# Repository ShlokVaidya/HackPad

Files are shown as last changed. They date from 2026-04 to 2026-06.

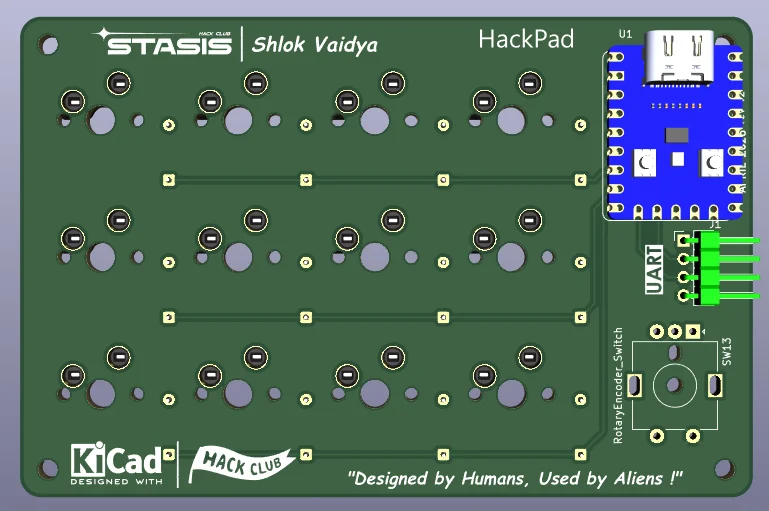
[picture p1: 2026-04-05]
PDFs/1775170877334-m3it0k.webp

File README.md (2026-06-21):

# HackPad

A 12-key macropad I built as my second hardware project for Stasis, designed to pair with my 60% keyboard for editing, shortcuts, media control, etc...

Hi there, this is my fully custom keypad from scratch, and I tried to keep it clean, practical, and actually buildable.

## Demo Video

<video src="./HackPad.mp4" controls width="1080">
  Your browser does not support embedded videos. You can watch the demo here: <a href="./HackPad.mp4">HackPad.mp4</a>.
</video>

[Open the demo video](./HackPad.mp4)

Note: The demo vid is working but u need to download to view it as it exceeds the 100mb Github limit. 

## Quick Project Summary

- Project: 3x4 macropad + rotary encoder
- MCU: RP2040 Zero
- Switches: 12x MX-style
- Extra input: 1x EC11 rotary encoder with push switch
- Matrix: 3 rows x 4 columns
- PCB size target: about 100mm x 65mm
- Case workflow: KiCad PCB export -> Onshape assembly -> custom bottom case + plate

## Why I Made This

I wanted a dedicated macropad next to my keyboard for common shortcuts (copy/paste, app switching, media, timeline scrubbing, etc.) and I wanted to learn the full flow:

1. keyboard layout planning
2. schematic capture
3. PCB routing
4. case CAD around real board geometry

## Features

- 12 programmable keys (MX style)
- Rotary encoder with click for volume/scroll/tool size/etc.
- RP2040-based and easy to firmware-program
- Through-hole diodes for matrix
- UART header exposed
- Custom silkscreen logos for personality

## Bill of Materials (BOM)

From [production/bom.csv](production/bom.csv):

| Item | Qty | Notes |
|---|---:|---|
| RP2040 Zero module | 1 | Main controller |
| MX-style switches | 12 | 1u keys |
| 1N4148 diodes | 12 | Matrix diodes |
| EC11 rotary encoder (with switch) | 1 | Knob + click |
| 1x4 right-angle pin header | 1 | UART / expansion |

## Design Files Included

- Schematic: [PCB/HackPad.kicad_sch](PCB/HackPad.kicad_sch)
- PCB: [PCB/HackPad.kicad_pcb](PCB/HackPad.kicad_pcb)
- KiCad project: [PCB/HackPad.kicad_pro](PCB/HackPad.kicad_pro)
- Layout JSON: [PCB/keyboard-layout.json](PCB/keyboard-layout.json)
- Plate DXF: [PCB/plate.dxf](PCB/plate.dxf)
- CAD model: [CAD/HackPad.step](CAD/HackPad.step)
- Production files:
	- [production/bom.csv](production/bom.csv)
	- [production/positions.csv](production/positions.csv)
	- [production/designators.csv](production/designators.csv)
	- [production/netlist.ipc](production/netlist.ipc)

## Firmware

KMK firmware for this board is included in:

- [firmware/kmk/code.py](firmware/kmk/code.py)
- [firmware/kmk/README.md](firmware/kmk/README.md)

It is preconfigured for the exact matrix and encoder pins used in this PCB.

## Progress Pictures

### Research

Research start / Stasis planning

### Schematic Stage

Keyboard layout planning

Schematic routing

### PCB Stage

PCB routing

PCB front silkscreen

PCB back silkscreen

### CAD / Case Stage

CAD view 1

CAD view 2

CAD view 3

CAD view 4

CAD view 5

CAD view 6

## Time Spent (from Journal)

- Research: ~0.33h
- Schematic: ~2.25h
- PCB: ~3.25h
- CAD: ~3.45h

Total logged so far: ~9.3h

## What I Learned

- Importing the actual PCB into CAD early saves a lot of pain later.
- Matrix labeling in schematic makes routing way less confusing.
- Tiny mechanical details (insert depth, nut traps, plate thickness) matter a lot more than expected.
- Silkscreen art is optional, but morale is not.

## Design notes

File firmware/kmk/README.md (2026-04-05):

# HackPad Advanced Firmware (KMK)

This folder contains an advanced default firmware for the RP2040-Zero-based HackPad.

## What You Get

- Correct matrix pin mapping from your PCB
- Rotary encoder support (turn + click)
- 4 layers: Base, Nav, Media, System
- Tap-dance (`ESC` on single tap, `` ` `` on double tap)
- Layer-tap keys (tap sends key, hold changes layer)
- Chord combos:
  - `Copy + Paste` -> `Select All`
  - `Undo + Redo` -> `Save`

## Pin Mapping (from KiCad)

- Columns: `GP14 GP15 GP26`
- Rows: `GP27 GP28 GP29 GP13`
- Encoder A/B/SW: `GP10 GP11 GP12`

## Install Steps

1. Flash CircuitPython to the RP2040 Zero.
2. Download KMK and copy the `kmk` folder to the CIRCUITPY drive.
3. Copy [firmware/kmk/code.py](code.py) to the root of CIRCUITPY as `code.py`.
4. Replug the board.

## Layer Overview

- `Layer 0 (Base)`: editing shortcuts and layer access
- `Layer 1 (Nav)`: arrows, home/end, page movement
- `Layer 2 (Media)`: media transport and volume
- `Layer 3 (System)`: function keys and reset/boot helpers

The bottom row of Layer 0 is layer-tap:

- Left key: tap `Space`, hold Layer 1
- Middle key: tap `Enter`, hold Layer 2
- Right key: tap `Tab`, hold Layer 3

## Notes

- If the matrix scans inverted on first boot, switch
  `DiodeOrientation.ROW2COL` to `DiodeOrientation.COL2ROW` in [firmware/kmk/code.py](code.py).
- `KC.BOOT` and `KC.RESET` are provided on Layer 3 for recovery/reflash flows.

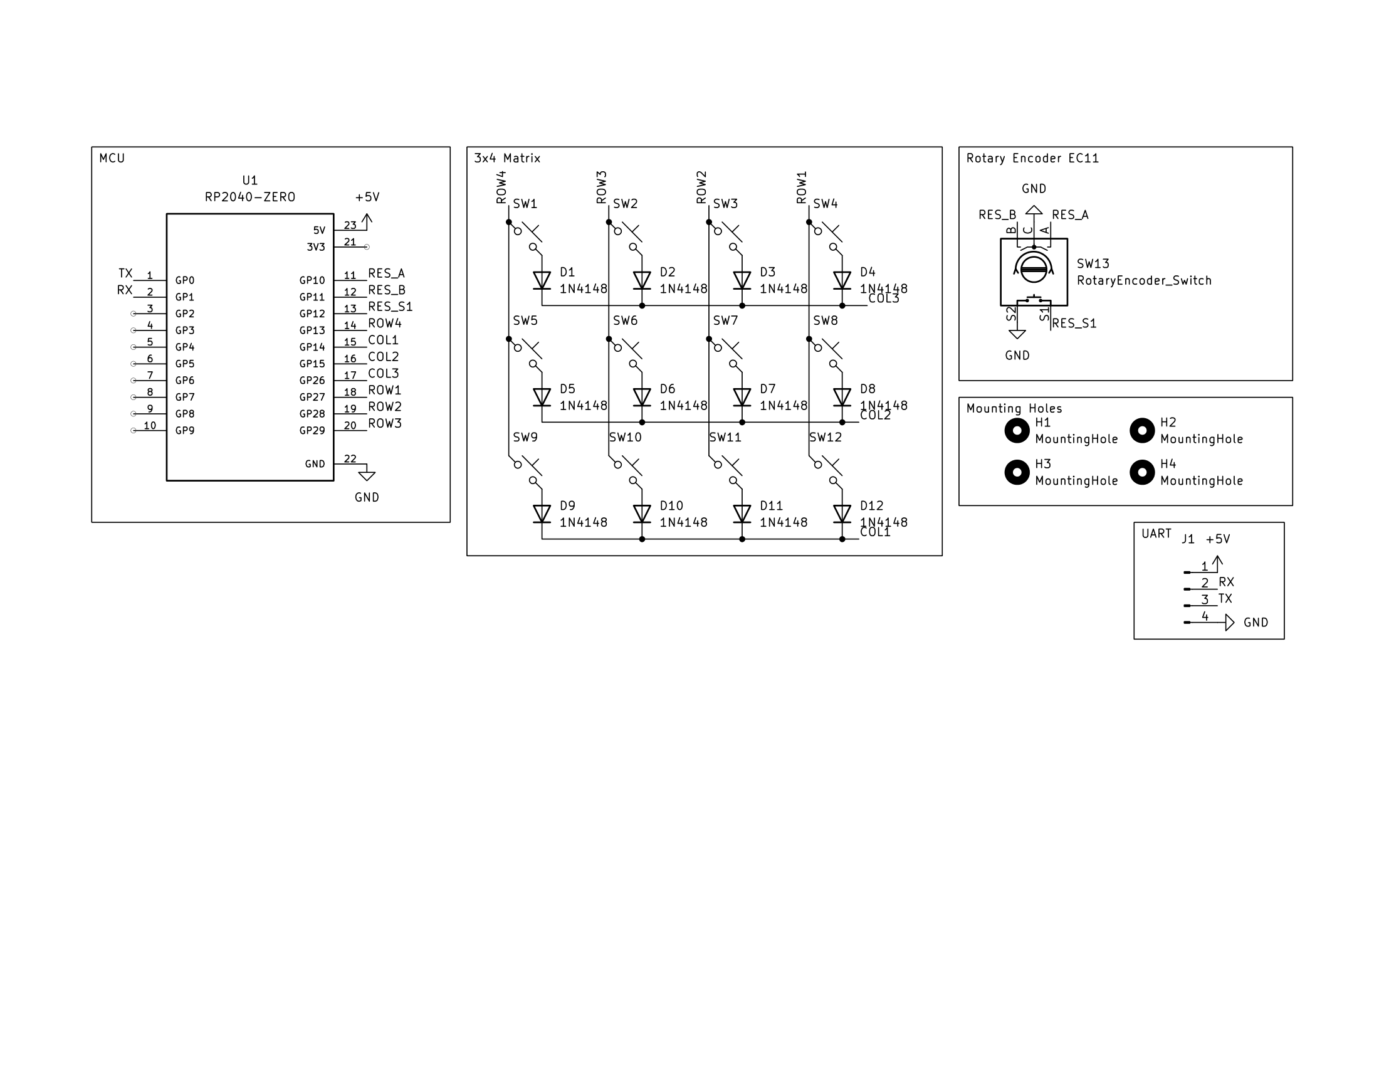
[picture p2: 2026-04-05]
PDFs/sch.png

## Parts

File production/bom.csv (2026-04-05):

Designator | Footprint | Quantity | Value | LCSC Part #
D1, D10, D11, D12, D2, D3, D4, D5, D6, D7, D8, D9 | D_DO-35_SOD27_P7.62mm_Horizontal | 12 | 1N4148
J1 | PinHeader_1x04_P2.54mm_Horizontal | 1 | Conn_01x04_Pin
SW1, SW10, SW11, SW12, SW2, SW3, SW4, SW5, SW6, SW7, SW8, SW9 | SW_MX_HS_KS-2P02B01-01_1u | 12 | SW_Push_45deg
SW13 | RotaryEncoder_Alps_EC11E-Switch_Vertical_H20mm_MountingHoles | 1 | RotaryEncoder_Switch
U1 | MODULE_RP2040-ZERO | 1 | RP2040-ZERO

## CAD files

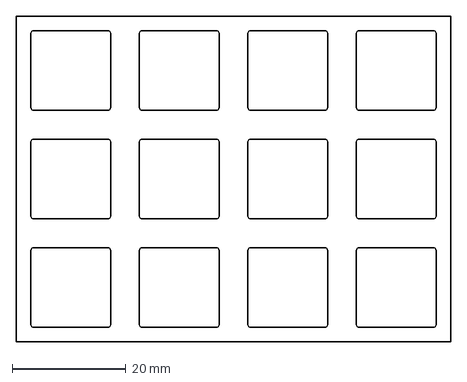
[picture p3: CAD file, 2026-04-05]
PCB/plate.dxf
76.2 x 57.1 mm

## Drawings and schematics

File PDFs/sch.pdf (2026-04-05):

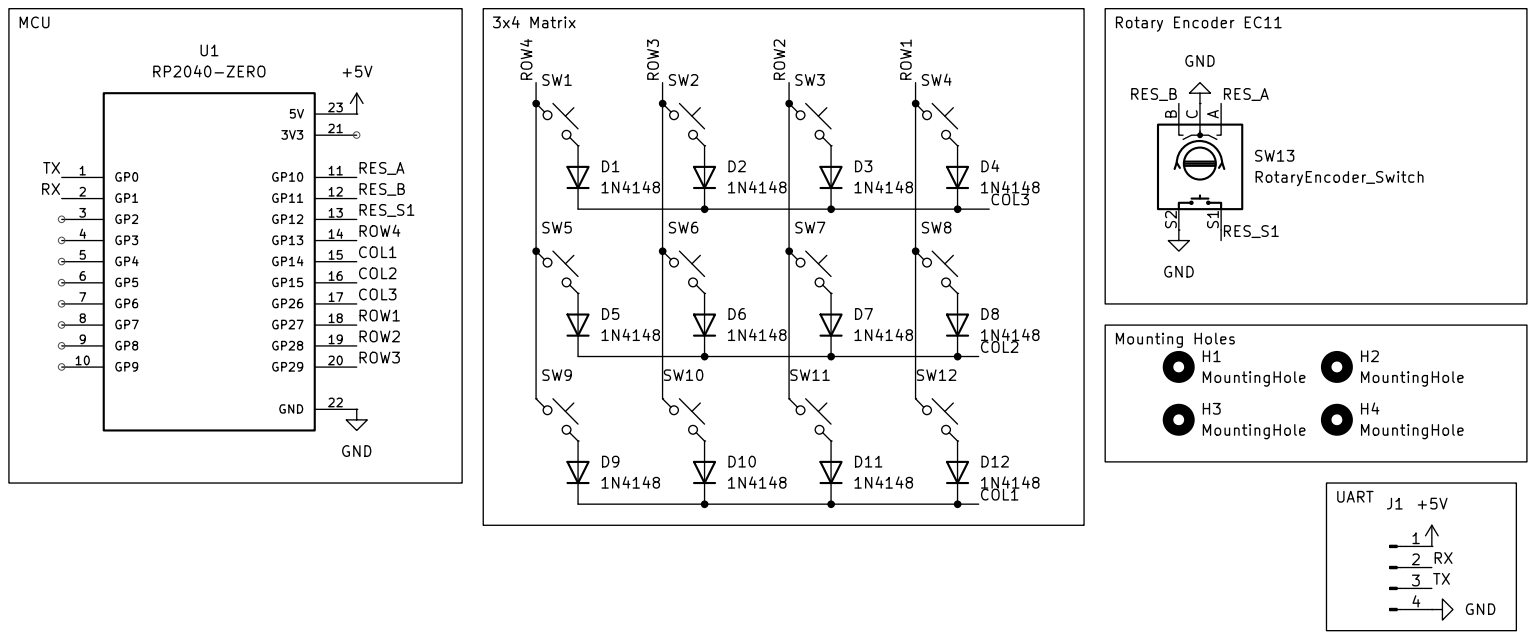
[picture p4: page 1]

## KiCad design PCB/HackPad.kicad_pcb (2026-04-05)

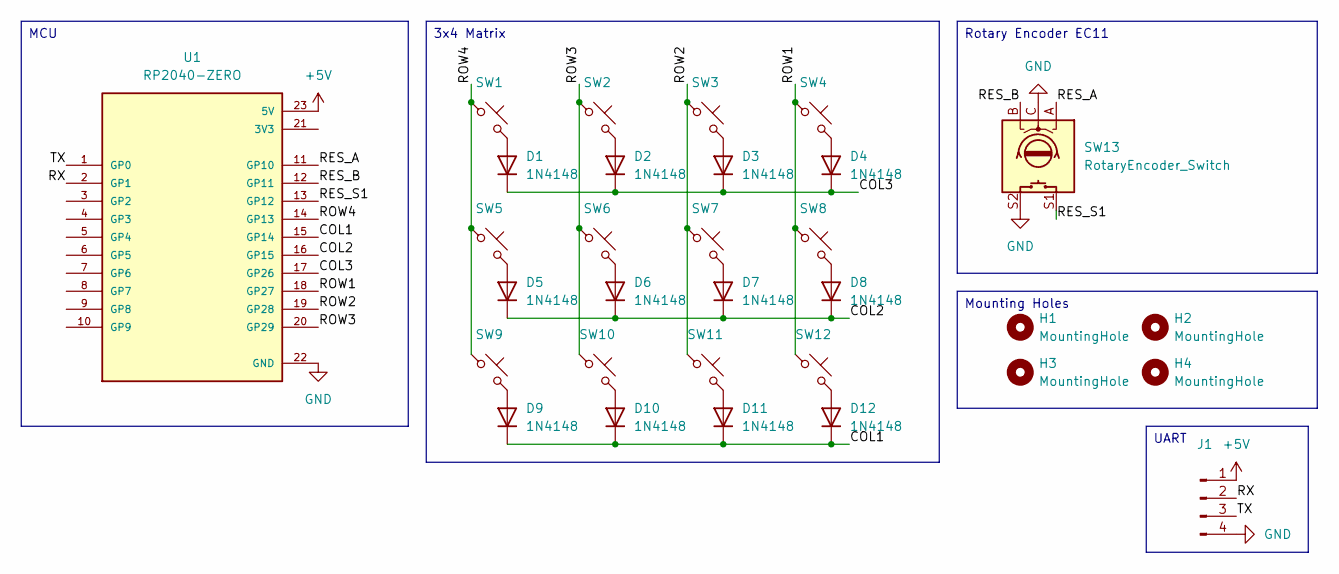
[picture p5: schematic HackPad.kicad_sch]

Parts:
D1, D2, D3, D4, D5, D6, D7, D8, D9, D10, D11, D12: 1N4148; D_DO-35_SOD27_P7.62mm_Horizontal
H1, H2, H3, H4: MountingHole; MountingHole_2.7mm_M2.5
J1: Conn_01x04_Pin; PinHeader_1x04_P2.54mm_Horizontal
SW1, SW2, SW3, SW4, SW5, SW6, SW7, SW8, SW9, SW10, SW11, SW12: SW_Push_45deg; SW_MX_HS_KS-2P02B01-01_1u
SW13: RotaryEncoder_Switch; RotaryEncoder_Alps_EC11E-Switch_Vertical_H20mm_MountingHoles
U1: RP2040-ZERO; MODULE_RP2040-ZERO; PARTREV NA

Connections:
+5V: J1.1, U1.23 (5V)
/COL1: D9.1 (K), D10.1 (K), D11.1 (K), D12.1 (K), U1.15 (GP14)
/COL2: D5.1 (K), D6.1 (K), D7.1 (K), D8.1 (K), U1.16 (GP15)
/COL3: D1.1 (K), D2.1 (K), D3.1 (K), D4.1 (K), U1.17 (GP26)
/RES_A: SW13.A, U1.11 (GP10)
/RES_B: SW13.B, U1.12 (GP11)
/RES_S1: SW13.S1, U1.13 (GP12)
/ROW1: SW4.1, SW8.1, SW12.1, U1.18 (GP27)
/ROW2: SW3.1, SW7.1, SW11.1, U1.19 (GP28)
/ROW3: SW2.1, SW6.1, SW10.1, U1.20 (GP29)
/ROW4: SW1.1, SW5.1, SW9.1, U1.14 (GP13)
/RX: J1.2, U1.2 (GP1)
/TX: J1.3, U1.1 (GP0)
GND: J1.4, SW13.C, SW13.S2, U1.22 (GND)
unnamed: D1.2 (A), SW1.2
unnamed: D2.2 (A), SW2.2
unnamed: D3.2 (A), SW3.2
unnamed: D4.2 (A), SW4.2
unnamed: D5.2 (A), SW5.2
unnamed: D6.2 (A), SW6.2
unnamed: D7.2 (A), SW7.2
unnamed: D8.2 (A), SW8.2
unnamed: D9.2 (A), SW9.2
unnamed: D10.2 (A), SW10.2
unnamed: D11.2 (A), SW11.2
unnamed: D12.2 (A), SW12.2

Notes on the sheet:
MCU
Mounting Holes
3x4 Matrix
UART
Rotary Encoder EC11

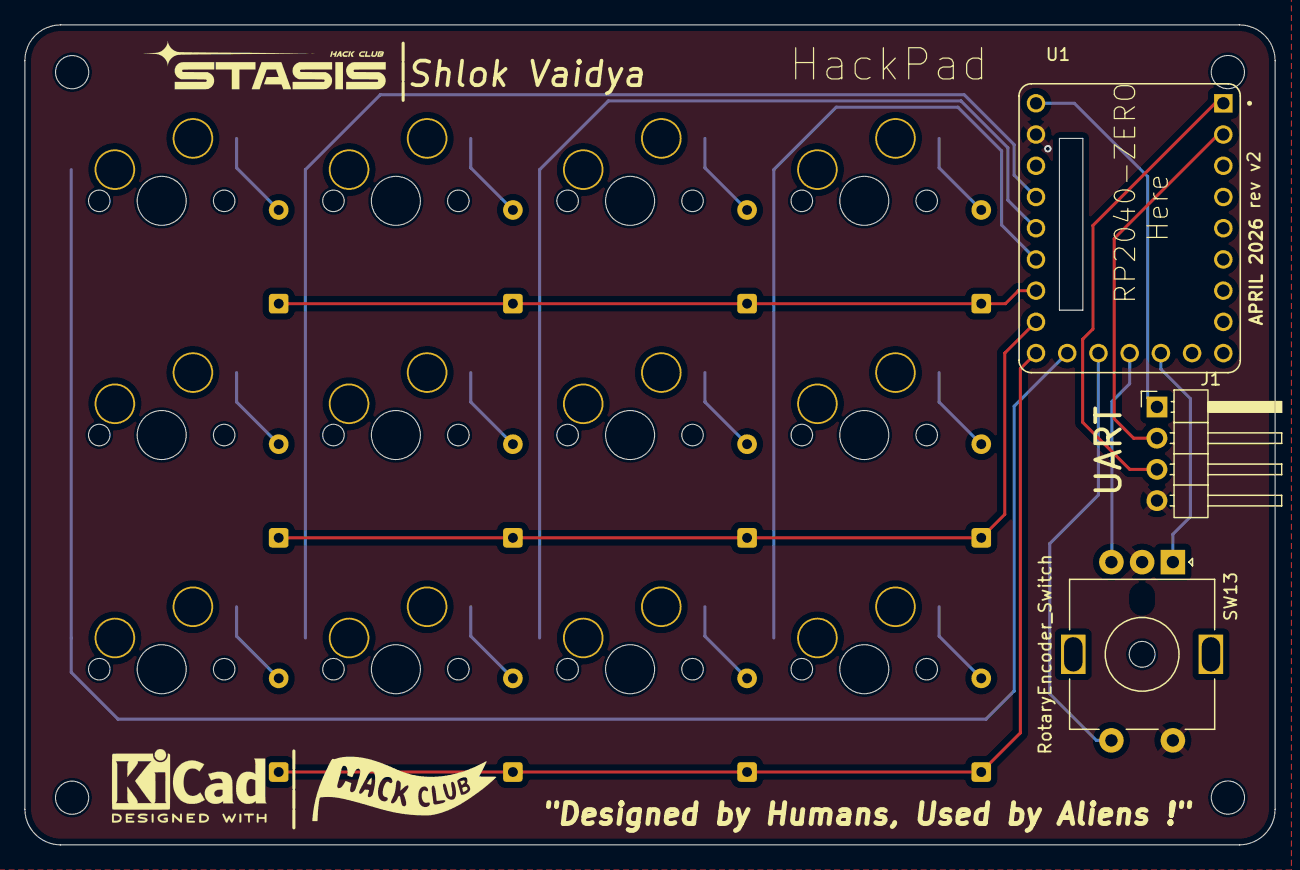
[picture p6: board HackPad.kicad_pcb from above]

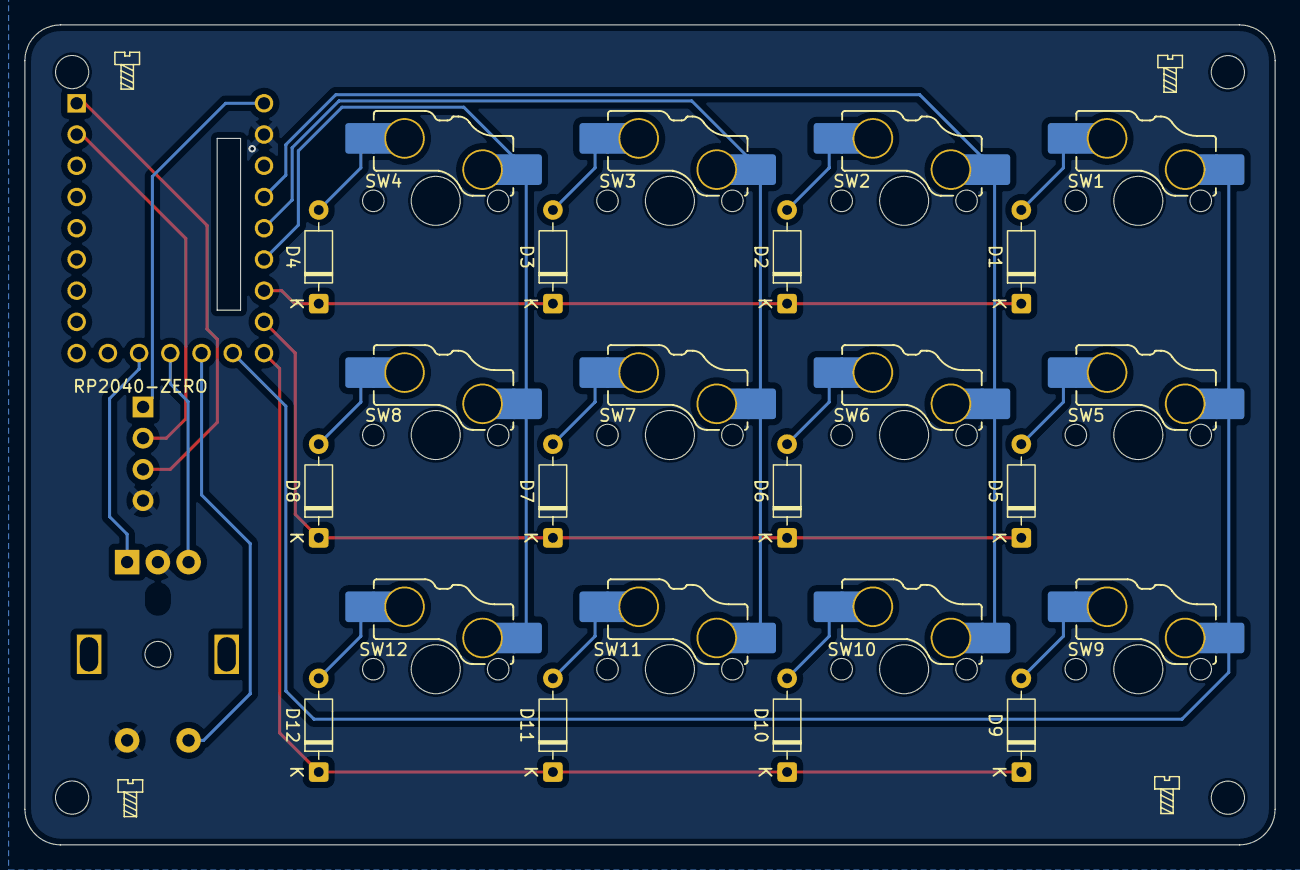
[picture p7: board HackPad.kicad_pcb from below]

Board: 2 copper layers, 101.7 x 66.7 mm, 33 parts (24 on the bottom side), 26 nets.

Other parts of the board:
H: MountingHole; MountingHole_2.7mm_M2.5
Pogo: LOGO; HackClub

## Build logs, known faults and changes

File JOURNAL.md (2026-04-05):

<!--
  This journal is auto generated by Stasis.
-->

# 4/4/2026 3 PM - CADDING

_Time spent: 3.45h_

For designing the case, I chose Onshape because it’s simple to use and performs better on my system, especially since I’m dealing with a GPU bottleneck.

I started by creating the base, i.e., the bottom case, and then assembled it in Onshape by importing the PCB from KiCad along with all its components to ensure precise alignment and accuracy. Once the bottom case was finalized, I downloaded the plate design from the ai03 Plate Generator and imported the .DXF file into a sketch. I then modified the plate to match the case dimensions, ensuring the plate thickness was exactly 1.4 mm.

After completing the plate, I assembled everything again and made a few aesthetic improvements. Finally, I fine-tuned the dimensions for the cutouts, including spaces for heat inserts, screws, and nuts.




















# 4/2/2026 11 PM - PCB

_Time spent: 3.25h_

Next, I moved on to PCB routing. I started by using the keyboard auto-layout for the 12 MX switches, then set the board outline to 101.7 × 66.7 mm. After that, I placed the MCU and the EC11 rotary encoder, and finally added the UART pins.



 Feeling the board being a bit boring and empty, I added some silkscreen logo adding color to the PCB 

Front


Back






# 4/2/2026 10 PM - Schematic

_Time spent: 2.25h_

Next I started with Schematics, I choose KiCAD as its free and has a huge communtiy resources. 

***
### Layout
 I started with the [keyboard layout](https://www.keyboard-layout-editor.com/) and decided to go with 3x4 matrix grid



***
### Downloading the required footprint
 Next I started downloading the required footprint like the RP2040-zero from waveshare, and some logos, like HackClub and Stasis. Converting it into silkscreen. 

***
### Placing the footprint
 I started routing the MCU and the Matrix grid first using labels. Then, routed other components 

sch

***




# 4/2/2026 10 PM - Reasearch

_Time spent: 0.3333333333333333h_

## Project Specifications
 I decided my 2nd project would be a HackPad pairing it with my 60% Keyboard. 

Specs
- RP2040 Zero - MCU
- 12x MX style Switches (3x4 Matric)
- 1x EC11 Rotary Encoder + Switch
- 1x UART pin
- 100x65 PCB dimension
- x4 M2.5 Mounting holes
- 
***

stasis-logo
***



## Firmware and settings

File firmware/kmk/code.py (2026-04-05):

import board

from kmk.kmk_keyboard import KMKKeyboard
from kmk.keys import KC
from kmk.modules.combos import Chord, Combos
from kmk.modules.encoder import EncoderHandler
from kmk.modules.holdtap import HoldTap
from kmk.modules.layers import Layers
from kmk.modules.tapdance import TapDance
from kmk.scanners import DiodeOrientation


keyboard = KMKKeyboard()

# Matrix from PCB netlist:
# COL1=GP14, COL2=GP15, COL3=GP26
# ROW1=GP27, ROW2=GP28, ROW3=GP29, ROW4=GP13
keyboard.col_pins = (board.GP14, board.GP15, board.GP26)
keyboard.row_pins = (board.GP27, board.GP28, board.GP29, board.GP13)
keyboard.diode_orientation = DiodeOrientation.ROW2COL

layers = Layers()
holdtap = HoldTap()
tapdance = TapDance()
combos = Combos()
encoder_handler = EncoderHandler()

keyboard.modules = [layers, holdtap, tapdance, combos, encoder_handler]


# Common aliases used in keymap and combos.
UNDO = KC.LCTL(KC.Z)
REDO = KC.LCTL(KC.Y)
CUT = KC.LCTL(KC.X)
COPY = KC.LCTL(KC.C)
PASTE = KC.LCTL(KC.V)
SAVE = KC.LCTL(KC.S)
FIND = KC.LCTL(KC.F)
SELECT_ALL = KC.LCTL(KC.A)

TD_ESC_GRV = KC.TD(KC.ESC, KC.GRV)

# Tap for space, hold for NAV layer.
LT_NAV = KC.LT(1, KC.SPC)
# Tap for enter, hold for MEDIA layer.
LT_MEDIA = KC.LT(2, KC.ENT)
# Tap for tab, hold for SYSTEM layer.
LT_SYS = KC.LT(3, KC.TAB)


# Chords on BASE layer:
# COPY + PASTE -> SELECT_ALL
# UNDO + REDO -> SAVE
combos.combos = [
	Chord((COPY, PASTE), SELECT_ALL),
	Chord((UNDO, REDO), SAVE),
]


# Encoder pins from PCB netlist:
# RES_A=GP10, RES_B=GP11, RES_S1=GP12
encoder_handler.pins = ((board.GP10, board.GP11, board.GP12, False),)

# Per-layer encoder map: (ccw, cw, press)
encoder_handler.map = [
	((KC.VOLD, KC.VOLU, KC.MUTE),),
	((KC.LEFT, KC.RIGHT, KC.ENT),),
	((KC.MPRV, KC.MNXT, KC.MPLY),),
	((KC.PGDN, KC.PGUP, KC.DEL),),
]


keyboard.keymap = [
	# Layer 0: BASE (editing macros)
	[
		TD_ESC_GRV,
		CUT,
		COPY,
		PASTE,
		UNDO,
		REDO,
		SAVE,
		FIND,
		KC.INS,
		LT_NAV,
		LT_MEDIA,
		LT_SYS,
	],
	# Layer 1: NAV
	[
		KC.HOME,
		KC.UP,
		KC.END,
		KC.LEFT,
		KC.DOWN,
		KC.RIGHT,
		KC.PGUP,
		KC.PGDN,
		KC.DEL,
		KC.TRNS,
		KC.TRNS,
		KC.TRNS,
	],
	# Layer 2: MEDIA
	[
		KC.MPRV,
		KC.MPLY,
		KC.MNXT,
		KC.VOLD,
		KC.MUTE,
		KC.VOLU,
		KC.F11,
		KC.F12,
		KC.PSCR,
		KC.TRNS,
		KC.TRNS,
		KC.TRNS,
	],
	# Layer 3: SYSTEM / utilities
	[
		KC.F1,
		KC.F2,
		KC.F3,
		KC.F4,
		KC.F5,
		KC.F6,
		KC.F7,
		KC.F8,
		KC.CAPS,
		KC.BOOT,
		KC.RESET,
		KC.NO,
	],
]


if __name__ == "__main__":
	keyboard.go()
